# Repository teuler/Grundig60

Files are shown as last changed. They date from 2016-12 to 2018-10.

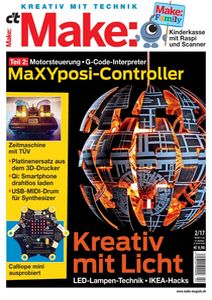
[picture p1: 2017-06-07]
pictures/Make02-17.jpg

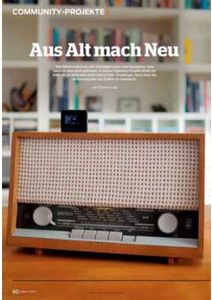
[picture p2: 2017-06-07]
pictures/Make02-17_S61.jpg

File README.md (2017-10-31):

# Grundig60

Converting an old radio from the 60ties (Grundig typ 92) into a DAB radio.

See [wiki](https://github.com/teuler/Grundig60/wiki) for details (German only, sorry).

### Release Notes

* 2017-10-31 - Added two new features: (1) programs are better distributed across the available capacitance range of the station dial, and (2) a function was added to mute the radio during the commercial break until the news starts.
* 2017-07-23 - Bug fix: Recall last station when radio is switched on and "Ton" dial is clamping the station (see below).
* 2017-06-07 - Added [reference](https://github.com/teuler/Grundig60/wiki) to a short presentation as Community Project in the German Make-Magzin 02/2017.
* 2017-05-07 - Added a work-around for the problem that when too many stations are found, the radio tends to oscillate between stations due to the sensitve (capacitative) station dial. Now the "Ton" dial can be used to "clamp" the selected station (for details, see [wiki](https://github.com/teuler/Grundig60/wiki/Endzustand)).
* 2016-12-30 - First "finale" version of the software.
* 2016-12-14 - Implemented a procedure for DAB autoseek, including (German) instructions on the OLED display. Partially solved the problem with the high sensitivity of the station dial; this fix prevents the radio from jumping back and forth between stations.

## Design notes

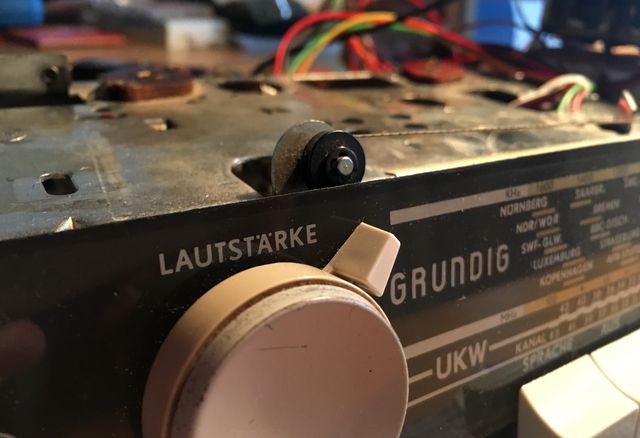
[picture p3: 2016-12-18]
pictures/pic041.jpg

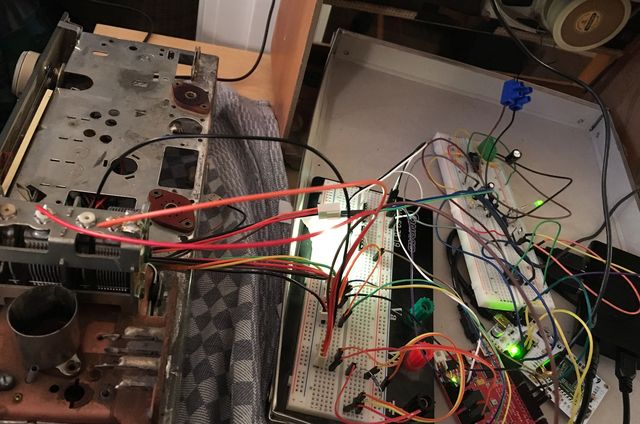
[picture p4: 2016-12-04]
pictures/pic021.jpg

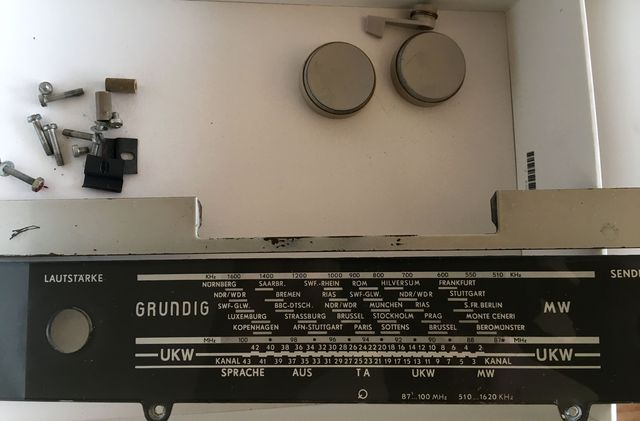
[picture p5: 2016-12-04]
pictures/pic011.jpg

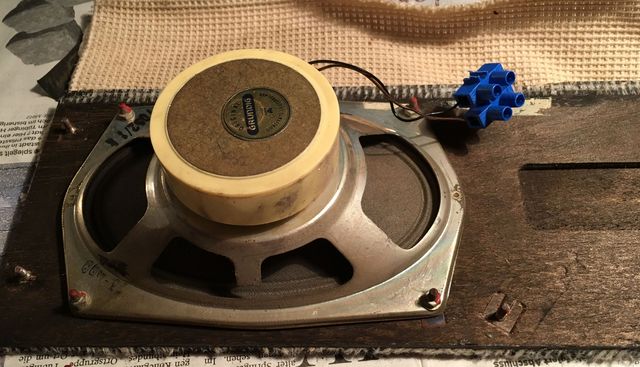
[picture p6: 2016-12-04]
pictures/pic028.jpg

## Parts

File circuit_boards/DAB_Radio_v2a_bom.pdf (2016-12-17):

# Bill of Materials: DAB_Radio_v2a.fzz

E:/User/Dropbox/__ROS/__Circuit boards/board_DAB radio/DAB_Radio_v2a.fzz
Samstag, Dezember 17 2016, 17:52:00

# Assembly List

Label | Part Type | Properties
aux | Audio Jack (TRS)
| 3.5mm | Paket PG203J [THT]; Größe 3.5 mm; Variante variant 1; channels Stereo (TRS)
C1 | Electrolytic
| Capacitor | Paket 100 mil [THT, electrolytic]; Kapazität 220µF; Spannung 6.3V
C2 | Electrolytic
| Capacitor | Paket 100 mil [THT, electrolytic]; Kapazität 1µF; Spannung 6.3V
C3 | Electrolytic
| Capacitor | Paket 100 mil [THT, electrolytic]; Kapazität 1µF; Spannung 6.3V
C4 | Electrolytic
| Capacitor | Paket 100 mil [THT, electrolytic]; Kapazität 1µF; Spannung 6.3V
C5 | Electrolytic
| Capacitor | Paket 100 mil [THT, electrolytic]; Kapazität 1µF; Spannung 6.3V
C6 | Ceramic Capacitor | Paket 100 mil [THT, multilayer]; Kapazität 0.47µF; Spannung 6.3V
C7 | Ceramic Capacitor | Paket 100 mil [THT, multilayer]; Kapazität 0.47µF; Spannung 6.3V
C8 | Electrolytic
| Capacitor | Paket 100 mil [THT, electrolytic]; Kapazität 1µF; Spannung 6.3V

### DAB radio

shield_v1 | Seeeduino Mega | input voltage 6-20V; clock speed 16 MHz; operating voltage 3.3V / 5V
IC1 | IC | Beinchenabstand 300mil; Paket DIP (Dual Inline) [THT]; Beinchen 16; true;
| | Chip-Beschriftung IC; Lochgröße 1.0mm,0.508mm; Bauteilnummer TDA7053A
IC2 | Basic FET
| P-Channel | Paket TO220 [THT]; Typ p-channel; Bauteilnummer IRF5305
IC3 | IC3 | Beinchenabstand 300mil; Paket DIP (Dual Inline) [THT]; Beinchen 10; true;
| | Chip-Beschriftung IC3; Lochgröße 1.0mm,0.508mm; Bauteilnummer ST3002H5W
J10 | Generic female
| header - 4 pins | Beinchenabstand 0.1in (2.54mm); Beinchen 4; Paket THT; Form ♀ (female);
| | Lochgröße 1.0mm,0.508mm; row single
J11 | Generic female
| header - 2 pins | Beinchenabstand 0.1in (2.54mm); Beinchen 2; Paket THT; Form ♀ (female);
| | Lochgröße 1.0mm,0.508mm; row single
J12 | Generic female
| header - 6 pins | Beinchenabstand 0.1in (2.54mm); Beinchen 6; Paket THT; Form ♀ (female);
| | Lochgröße 1.0mm,0.508mm; row single
J1_DAB | Generic female
| header - 4 pins | Beinchenabstand 0.1in (2.54mm); Beinchen 4; Paket THT; Form ♀ (female);
| | Lochgröße 1.0mm,0.508mm; row single
Fritzing Bill of Materials | file:///E:/User/Dropbox/__GIT/Grundig60/circuit_board/DAB_Radio_...
1 von 3 | 17.12.2016 18:00

Label | Part Type | Properties
J2_LED | Generic female

### header - 3 pins

Beinchenabstand 0.1in (2.54mm); Beinchen 3; Paket THT; Form ♀ (female); Lochgröße 1.0mm,0.508mm; row single

J3_power | Generic female

### header - 2 pins

Beinchenabstand 0.1in (2.54mm); Beinchen 2; Paket THT; Form ♀ (female); Lochgröße 1.0mm,0.508mm; row single

J4 | Generic female

### header - 3 pins

Beinchenabstand 0.1in (2.54mm); Beinchen 3; Paket THT; Form ♀ (female); Lochgröße 1.0mm,0.508mm; row single

J6_I2C | Generic female

### header - 4 pins

Beinchenabstand 0.1in (2.54mm); Beinchen 4; Paket THT; Form ♀ (female); Lochgröße 1.0mm,0.508mm; row single

J7 | Generic female

### header - 4 pins

Beinchenabstand 0.1in (2.54mm); Beinchen 4; Paket THT; Form ♀ (female); Lochgröße 1.0mm,0.508mm; row single

J8 | Generic female

### header - 2 pins

Beinchenabstand 0.1in (2.54mm); Beinchen 2; Paket THT; Form ♀ (female); Lochgröße 1.0mm,0.508mm; row single

J9 | Generic female

### header - 3 pins

Beinchenabstand 0.1in (2.54mm); Beinchen 3; Paket THT; Form ♀ (female); Lochgröße 1.0mm,0.508mm; row single

L

### Screw terminal - 2 pins

Beinchenabstand 0.1in (2.54mm); Beinchen 2; Paket THT; Lochgröße 1.0mm,0.508mm

LED1 | Green (570nm) LED | Paket 3 mm [THT]; leg yes; Farbe Green (570nm)

R

### Screw terminal - 2 pins

Beinchenabstand 0.1in (2.54mm); Beinchen 2; Paket THT; Lochgröße 1.0mm,0.508mm

R1 | 10kΩ Resistor | Beinchenabstand 400 mil; Paket THT; bands 4; Toleranz ±5%; Widerstand 10kΩ
R2 | 1kΩ Resistor | Beinchenabstand 400 mil; Paket THT; bands 4; Toleranz ±5%; Widerstand 1kΩ
R3 | 330Ω Resistor | Beinchenabstand 400 mil; Paket THT; bands 4; Toleranz ±5%; Widerstand 330Ω
R4 | 10kΩ Resistor | Beinchenabstand 400 mil; Paket THT; bands 4; Toleranz ±5%; Widerstand 10kΩ
R5 | 10kΩ Resistor | Beinchenabstand 400 mil; Paket THT; bands 4; Toleranz ±5%; Widerstand 10kΩ
R6 | 100kΩ Resistor | Beinchenabstand 400 mil; Paket THT; bands 4; Toleranz ±5%; Widerstand 100kΩ
R7 | 8.2kΩ Resistor | Beinchenabstand 400 mil; Paket THT; bands 4; Toleranz ±5%; Widerstand 8.2kΩ
R8 | 8.2kΩ Resistor | Beinchenabstand 400 mil; Paket THT; bands 4; Toleranz ±5%; Widerstand 8.2kΩ
R9 | 1MΩ Resistor | Beinchenabstand 400 mil; Paket THT; bands 4; Toleranz ±5%; Widerstand 1MΩ
R10 | 1MΩ Resistor | Beinchenabstand 400 mil; Paket THT; bands 4; Toleranz ±5%; Widerstand 1MΩ
radio | Audio Jack (TRS)
3.5mm

Paket PG203J [THT]; Größe 3.5 mm; Variante variant 1; channels Stereo (TRS)

# Shopping List

Amount | Part Type | Properties
2 | Audio Jack (TRS) | Paket PG203J [THT]; Größe 3.5 mm; Variante variant 1; channels Stereo (TRS)
2 von 3 | 17.12.2016 18:00

Amount | Part Type | Properties
| 3.5mm

### 1 Electrolytic

| Capacitor | Paket 100 mil [THT, electrolytic]; Kapazität 220µF; Spannung 6.3V

### 5 Electrolytic

| Capacitor | Paket 100 mil [THT, electrolytic]; Kapazität 1µF; Spannung 6.3V
2 | Ceramic Capacitor | Paket 100 mil [THT, multilayer]; Kapazität 0.47µF; Spannung 6.3V
1 | Seeeduino Mega | input voltage 6-20V; clock speed 16 MHz; operating voltage 3.3V / 5V
1 | IC | Beinchenabstand 300mil; Paket DIP (Dual Inline) [THT]; Beinchen 16; true; Chip-Beschriftung IC; Lochgröße 1.0mm,0.508mm; Bauteilnummer TDA7053A
1 | Basic FET P-Channel | Paket TO220 [THT]; Typ p-channel; Bauteilnummer IRF5305
1 | IC3 | Beinchenabstand 300mil; Paket DIP (Dual Inline) [THT]; Beinchen 10; true; Chip-Beschriftung IC3; Lochgröße 1.0mm,0.508mm; Bauteilnummer ST3002H5W

### 4 Generic female

| header - 4 pins | Beinchenabstand 0.1in (2.54mm); Beinchen 4; Paket THT; Form ♀ (female); Lochgröße 1.0mm,0.508mm; row single

### 3 Generic female

| header - 2 pins | Beinchenabstand 0.1in (2.54mm); Beinchen 2; Paket THT; Form ♀ (female); Lochgröße 1.0mm,0.508mm; row single

### 1 Generic female

| header - 6 pins | Beinchenabstand 0.1in (2.54mm); Beinchen 6; Paket THT; Form ♀ (female); Lochgröße 1.0mm,0.508mm; row single

### 3 Generic female

| header - 3 pins | Beinchenabstand 0.1in (2.54mm); Beinchen 3; Paket THT; Form ♀ (female); Lochgröße 1.0mm,0.508mm; row single

### 2 Screw terminal - 2

| pins | Beinchenabstand 0.1in (2.54mm); Beinchen 2; Paket THT; Lochgröße 1.0mm,0.508mm
1 | Green (570nm) LED | Paket 3 mm [THT]; leg yes; Farbe Green (570nm)
3 | 10kΩ Resistor | Beinchenabstand 400 mil; Paket THT; bands 4; Toleranz ±5%; Widerstand 10kΩ
1 | 1kΩ Resistor | Beinchenabstand 400 mil; Paket THT; bands 4; Toleranz ±5%; Widerstand 1kΩ
1 | 330Ω Resistor | Beinchenabstand 400 mil; Paket THT; bands 4; Toleranz ±5%; Widerstand 330Ω
1 | 100kΩ Resistor | Beinchenabstand 400 mil; Paket THT; bands 4; Toleranz ±5%; Widerstand 100kΩ
2 | 8.2kΩ Resistor | Beinchenabstand 400 mil; Paket THT; bands 4; Toleranz ±5%; Widerstand 8.2kΩ
2 | 1MΩ Resistor | Beinchenabstand 400 mil; Paket THT; bands 4; Toleranz ±5%; Widerstand 1MΩ

Exported with Fritzing 0.9.3- http://fritzing.org

3 von 3 | 17.12.2016 18:00

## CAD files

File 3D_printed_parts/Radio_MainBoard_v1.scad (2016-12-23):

include <threads.scad>

b_xrim      = 3;
b_yrim      = 3;
b_dx        = 55;
b_dy        = 72;
b_thickness = 1.5;
b_shift     = 0;

scr_dz      = 6;
scr_dia     = 5;
scr_hole_d  = 3.0;
scr_hole2_d = 5;
pos_scr     = [[b_dx-3-b_xrim ,18+51-b_yrim,0],
               [b_dx-20,10,0],
               [b_dx-29-20,18-3,0],
               [13-b_xrim,b_dy-13-b_yrim,0]];

pos_b       = [-b_dx/2,-b_dy/2, 0];
pos_scr_off = [-b_dx/2,-b_dy/2, 0];


module board() {
 /* difference() {
        union() {
            for(pos=pos_scr) {
                rotate(0, [1,0,0]) translate(pos)
                translate(pos_scr_off)
                translate([scr_dia/2,scr_dia/2,h_from_tube -b_thickness*0.8])
                cylinder($fn=100, h=scr_dz+b_thickness/2, r=scr_dia/2);
            }
            translate(pos_b) 
            cube([b_dx, b_dy, b_thickness]);
        }
        union() {
            for(pos=pos_scr) {
                rotate(0, [1,0,0]) translate(pos) 
                translate(pos_scr_off)
                translate([scr_dia/2,scr_dia/2,-10])
                cylinder($fn=100, h=scr_dz*3, r=scr_hole2_d/2);
            }
            for(pos=pos_scr) {
                rotate(0, [1,0,0]) translate(pos) 
                translate(pos_scr_off)
                translate([scr_dia/2,scr_dia/2,h_from_tube -b_thickness*2])
                cylinder($fn=100, h=scr_dz*2, r=scr_hole_d/2);
            }
        }*/
    
    for(pos=pos_scr) {
        rotate(0, [1,0,0]) translate(pos)
        translate(pos_scr_off)
        translate([scr_dia/2,scr_dia/2,0.25])
        cylinder($fn=100, h=scr_dz+b_thickness, r=scr_dia/2);
    }
    translate(pos_b) 
    cube([b_dx, b_dy, b_thickness]);
}

module threads() {
    for(pos=pos_scr) {
        rotate(0, [1,0,0]) translate(pos) 
        translate(pos_scr_off)
        translate([scr_dia/2,scr_dia/2,-3])
        //cylinder($fn=100, h=scr_dz*2, r=scr_hole_d/2);
        metric_thread(diameter=2.5, pitch=0.45, length=scr_dz+b_thickness+5+10, internal=true);
    }
}

module holes() {
    rotate(0, [1,0,0])
    translate(pos_b)
    translate([b_dx-4,11,-10])
    cylinder($fn=100, h=20, r=4/2);

    rotate(0, [1,0,0])
    translate(pos_b)
    translate([25,27,-10])
    cylinder($fn=100, h=20, r=3/2);

    rotate(0, [1,0,0])
    translate(pos_b)
    translate([b_dx-13,46,-10])
    cylinder($fn=100, h=20, r=3/2);
    
    rotate(0, [1,0,0])
    translate(pos_b)
    translate([28-1.5,2,-10])
    cylinder($fn=100, h=20, r=4/2);

    translate(pos_b) 
    translate([b_dx+b_xrim-30,15,-5]) 
    cube([30, 30, 10]);

    translate(pos_b) 
    translate([-1,-1,-5]) 
    cube([7, 26, 10]);
}

module base() {
    difference() {
        board();
        union() {
            threads();    
            holes();
        }
    }
}

base();





/*
d_wall		= 1.25;
tol			= 0.2;

fr_dx		= 65 +2*d_wall;
fr_dy		= 140; //120 +d_wall;
fr_height  = 30;

lt_dx      = 20;

scr1_dia   = 7;
scr1_ctr_x = -8;
scr1_ctr_dy= 17;

scr2_dia   = 6;
scr_dy_wall= 25;
scr_dx_left= 15;
scr2_pos   = [[scr_dx_left+15,scr_dy_wall+2,d_wall/2], 
			 [scr_dx_left+42.5,scr_dy_wall+2,d_wall/2], 
              [scr_dx_left+15,scr_dy_wall+59,d_wall/2], 
              [scr_dx_left+42.5,scr_dy_wall+59,d_wall/2]];
scr2_height= 6;
scr2_h_dia = 3.0;
scr3_dia   = scr2_dia;
scr3_pos   = [[4,   110,   d_wall/2],
			 [4,   110+21,d_wall/2],			 
			 [4+57,110,   d_wall/2],
			 [4+57,110+21,d_wall/2]];
scr3_height= 11;
scr3_h_dia = scr2_h_dia;


led_dia    = 3;
led_pos    = [[1*fr_dx/6,scr1_ctr_dy/2+fr_height/2, -10],
   			 [3*fr_dx/6,scr1_ctr_dy/2+fr_height/2, -10],
			 [5*fr_dx/6,scr1_ctr_dy/2+fr_height/2, -10]];

bnc_dia    = 10;
bnc_pos    = [[1*fr_dx/6,fr_height/3, -10],
//			 [fr_dx/2,fr_height/3*2, -10-fr_dy]
			 [3*fr_dx/6,fr_height/3, -10]];

module Screw1Holes()
{
	_r		= scr1_dia/2 +tol;
	_x		= scr1_ctr_x;
	_y1		= fr_height/2 +scr1_ctr_dy/2;
	_y2		= fr_height/2 -scr1_ctr_dy/2;
	rotate(90, [1,0,0]) translate([_x,_y1,-10]) 
	cylinder($fn=100, h=20, r=_r);
	rotate(90, [1,0,0]) translate([_x,_y2,-10]) 
	cylinder($fn=100, h=20, r=_r);
};


module LEDHoles()
{
	_r		= led_dia/2 +tol/2;
    for(pos=led_pos) { 
		rotate(90, [1,0,0]) translate(pos) 
		cylinder($fn=100, h=9.5, r=_r);
	}
};

module LEDPosts()
{
	_r		= led_dia/2 +tol/2;
    for(pos=led_pos) { 
		rotate(90, [1,0,0]) translate(pos) translate([0,0,4])
		cylinder($fn=100, h=3+d_wall*2, r=_r+2);
	}
};


module BNCHoles()
{
	_r		= bnc_dia/2 +tol/2;
    for(pos=bnc_pos) { 
		difference() {
			rotate(90, [1,0,0]) translate(pos) 
			cylinder($fn=100, h=20, r=_r);
			rotate(90, [1,0,0]) translate([pos[0]-_r,pos[1]+4.8*_r/6,pos[2]])
			cube([2*_r,5,25]);
		}	
	}
};

module cableHoles()
{
	_x		= fr_dx/3*2;
	_y 		= fr_dx/7;
	rotate(90, [1,0,0]) translate([_x,_y,-fr_dy-10]) 
	cylinder($fn=100, h=20, r=7.5);
}

module FrontPlateHoles()
{
	LEDHoles();
	BNCHoles();
}

module BaseplateHoles()
{
    _dx   = fr_dx/4;
    _dy   = fr_dx/4;
    _f    = 1.4;
    _d    = 0.10*_dx;
    _z    = -5;
    _dyst = 1.65;
    _yoff = 0.3;
    for(i=[0,1.05,2,3.05]) {
	    translate([0.50*_dx-_d,(_yoff+_dyst*i)*_dx,_z]) cube([_dx*_f,_dy,10]);
    		translate([2.25*_dx-_d,(_yoff+_dyst*i)*_dx,_z]) cube([_dx*_f,_dy,10]);   
    }
}

module RC_Box()
{
	difference() 
	{
		difference()
		{
			cube([fr_dx, fr_dy, fr_height]);
			translate([d_wall,d_wall*2,d_wall]) cube([fr_dx-2*d_wall,fr_dy-3*d_wall,fr_height]);
		}
    		BaseplateHoles();
	}

    difference()
    {
		translate([-lt_dx,0,0]) cube([lt_dx, d_wall*2, fr_height]);
		Screw1Holes();
    }

	rotate(-90, [0,0,1])
    for(pos=scr2_pos) { 
		rotate(90, [0,0,1]) translate(pos) 
		difference() {
			cylinder($fn=100, h=scr2_height, r=scr2_dia/2);
			cylinder($fn=100, h=scr2_height+5, r=scr2_h_dia/2);
		}
	}
	rotate(-90, [0,0,1])
    for(pos=scr3_pos) { 
		rotate(90, [0,0,1]) translate(pos) 
		difference() {
			cylinder($fn=100, h=scr3_height, r=scr3_dia/2);
			cylinder($fn=100, h=scr3_height+5, r=scr3_h_dia/2);
		}
	}
	LEDPosts();
}

difference()
{
	RC_Box();
	FrontPlateHoles();
	cableHoles();
}
*/

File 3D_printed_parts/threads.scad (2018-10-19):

/*
 * Dan Kirshner - dan_kirshner@yahoo.com
 *
 * You are welcome to make free use of this software.  Retention of my 
 * authorship credit would be appreciated.
 *
 * Version 1.3.  2013-12-01   Correct loop over turns -- don't have early cut-off
 * Version 1.2.  2012-09-09   Use discrete polyhedra rather than linear_extrude()
 * Version 1.1.  2012-09-07   Corrected to right-hand threads!
 */

// Examples:
//metric_thread(8, 1, 10);
//english_thread(1/4, 20, 1);

// Rohloff hub thread:
//metric_thread(34, 1, 10, internal=true, n_starts=6);



//metric_thread(8, 2, 4);



// ----------------------------------------------------------------------------
pi = 3.14159265;


// ----------------------------------------------------------------------------
function segments(diameter) = min(50, ceil(diameter*6));


// ----------------------------------------------------------------------------
// internal - true = clearances for internal thread (e.g., a nut).
//            false = clearances for external thread (e.g., a bolt).
//            (Internal threads should be "cut out" from a solid using
//            difference()).
// n_starts - Number of thread starts (e.g., DNA, a "double helix," has
//            n_starts=2).  See wikipedia Screw_thread.
module metric_thread(diameter=8, pitch=1, length=1, internal=false, n_starts=1)
{
   // Number of turns needed.
   n_turns = floor(length/pitch);
   n_segments = segments(diameter);
   h = pitch * cos(30);

   union() {
      intersection() {
         // Start one below z = 0.  Gives an extra turn at each end.
         for (i=[-1*n_starts : n_turns+1]) {
            translate([0, 0, i*pitch]) {
               metric_thread_turn(diameter, pitch, internal, n_starts);
            }
         }

         // Cut to length.
         translate([0, 0, length/2]) {
            cube([diameter*1.1, diameter*1.1, length], center=true);
         }
      }

      // Solid center, including Dmin truncation.
      if (internal) {
         cylinder(r=diameter/2 - h*5/8, h=length, $fn=n_segments);
      } else {

         // External thread includes additional relief.
         cylinder(r=diameter/2 - h*5.3/8, h=length, $fn=n_segments);
      }
   }
}


// ----------------------------------------------------------------------------
// Input units in inches.
// Note: units of measure in drawing are mm!
module english_thread(diameter=0.25, threads_per_inch=20, length=1,
                      internal=false, n_starts=1)
{
   // Convert to mm.
   mm_diameter = diameter*25.4;
   mm_pitch = (1.0/threads_per_inch)*25.4;
   mm_length = length*25.4;

   echo(str("mm_diameter: ", mm_diameter));
   echo(str("mm_pitch: ", mm_pitch));
   echo(str("mm_length: ", mm_length));
   metric_thread(mm_diameter, mm_pitch, mm_length, internal, n_starts);
}


// ----------------------------------------------------------------------------
module metric_thread_turn(diameter, pitch, internal, n_starts)
{
   n_segments = segments(diameter);
   fraction_circle = 1.0/n_segments;
   for (i=[0 : n_segments-1]) {
      rotate([0, 0, i*360*fraction_circle]) {
         translate([0, 0, i*n_starts*pitch*fraction_circle]) {
            thread_polyhedron(diameter/2, pitch, internal, n_starts);
         }
      }
   }
}


// ----------------------------------------------------------------------------
// z (see diagram) as function of current radius.
// (Only good for first half-pitch.)
function z_fct(current_radius, radius, pitch)
   = 0.5*(current_radius - (radius - 0.875*pitch*cos(30)))
                                                       /cos(30);

// ----------------------------------------------------------------------------
module thread_polyhedron(radius, pitch, internal, n_starts)
{
   n_segments = segments(radius*2);
   fraction_circle = 1.0/n_segments;

   h = pitch * cos(30);
   outer_r = radius + (internal ? h/20 : 0); // Adds internal relief.
   //echo(str("outer_r: ", outer_r));


   inner_r = radius - 0.875*h; // Does NOT do Dmin_truncation - do later with
                               // cylinder.

   // Make these just slightly bigger (keep in proportion) so polyhedra will
   // overlap.
   x_incr_outer = outer_r * fraction_circle * 2 * pi * 1.005;
   x_incr_inner = inner_r * fraction_circle * 2 * pi * 1.005;
   z_incr = n_starts * pitch * fraction_circle * 1.005;

   /*    
    (angles x0 and x3 inner are actually 60 deg)

                          /\  (x2_inner, z2_inner) [2]
                         /  \
   (x3_inner, z3_inner) /    \
                  [3]   \     \
                        |\     \ (x2_outer, z2_outer) [6]
                        | \    /
                        |  \  /|
             z          |   \/ / (x1_outer, z1_outer) [5]
             |          |   | /
             |   x      |   |/
             |  /       |   / (x0_outer, z0_outer) [4]
             | /        |  /     (behind: (x1_inner, z1_inner) [1]
             |/         | /
    y________|          |/
   (r)                  / (x0_inner, z0_inner) [0]

   */

   x1_outer = outer_r * fraction_circle * 2 * pi;

   z0_outer = z_fct(outer_r, radius, pitch);
   //echo(str("z0_outer: ", z0_outer));

   //polygon([[inner_r, 0], [outer_r, z0_outer], 
   //        [outer_r, 0.5*pitch], [inner_r, 0.5*pitch]]);
   z1_outer = z0_outer + z_incr;

   // Rule for triangle ordering: look at polyhedron from outside: points must
   // be in clockwise order.
   polyhedron(
      points = [
                [-x_incr_inner/2, -inner_r, 0],                                    // [0]
                [x_incr_inner/2, -inner_r, z_incr],                    // [1]
                [x_incr_inner/2, -inner_r, pitch + z_incr],            // [2]
                [-x_incr_inner/2, -inner_r, pitch],                                // [3]

                [-x_incr_outer/2, -outer_r, z0_outer],                             // [4]
                [x_incr_outer/2, -outer_r, z0_outer + z_incr],         // [5]
                [x_incr_outer/2, -outer_r, pitch - z0_outer + z_incr], // [6]
                [-x_incr_outer/2, -outer_r, pitch - z0_outer]                      // [7]
               ],

      triangles = [
                [0, 3, 4],  // This-side trapezoid, bottom
                [3, 7, 4],  // This-side trapezoid, top

                [1, 5, 2],  // Back-side trapezoid, bottom
                [2, 5, 6],  // Back-side trapezoid, top

                [0, 1, 2],  // Inner rectangle, bottom
                [0, 2, 3],  // Inner rectangle, top

                [4, 6, 5],  // Outer rectangle, bottom
                [4, 7, 6],  // Outer rectangle, top

                [7, 2, 6],  // Upper rectangle, bottom
                [7, 3, 2],  // Upper rectangle, top

                [0, 5, 1],  // Lower rectangle, bottom
                [0, 4, 5]   // Lower rectangle, top
               ]
   );
}

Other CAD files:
3D_printed_parts/Radio_DAB_v2b.scad

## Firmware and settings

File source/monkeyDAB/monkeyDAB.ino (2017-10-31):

//--------------------------------------------------------------------------------
// project : monkeyDAB
// module  : monkeyDAB
//           DAB radio based on monkey DAB board
// author  : Thomas Euler
// history : 2016-10-08, created
//           2017-05-07, tone dial setting to "clamp" station
//           2017-07-15, check for station "clamp" only after checking for the 
//                       selected station at start-up
//
//--------------------------------------------------------------------------------
#define  GERMAN_TEXT
#define  USE_HSV
#include <WS2812.h>
#include <EEPROM.h>
#include <Wire.h>
#include <Adafruit_GFX.h>
#include <Adafruit_SSD1306.h>
#include "monkeyRadio.h"

//--------------------------------------------------------------------------------
// Global definitions
//
#define          SER_HOST           (*SerHostStream)
#define          SER_DEBUG_OUT      (*SerDebugStream)
#define          SER_MONKEY_RADIO   Serial1
#define          SER_DEBUG          Serial

//#define        LOG_INTERF_CHANGES 
//#define        LOG_CAP_TO_PROG    

//                                  0   -> TX0
//                                  1   -> RX0
#define          PIN_LED            2
#define          PIN_BUTTON_SPRACHE 3
//                                  4   -> DAB SHNT
//                                  5   -> DAB SHDN
#define          PIN_DISPLAY_RST    6
#define          PIN_DIAL_VC        7
//                                  8
//                                  10
#define          PIN_RELAY          11
#define          PIN_AMP_POWER      12
#define          PIN_CAP_IN         A0
#define          PIN_CAP_OUT        A1
//                                  A2
#define          PIN_DIAL_EXTEND    A3
#define          PIN_DIAL_TON       A4
#define          PIN_BUTTON_MW      A5
#define          PIN_BUTTON_UKW     A6
#define          PIN_BUTTON_TA      A7

#define          ID_LED_INFO        0
#define          ID_LED_INFO2       1
#define          LED_COUNT          2
#define          ID_COLOR_PLAYING   0
#define          ID_COLOR_TUNING    1
#define          ID_COLOR_STARTING  2
#define          ID_COLOR_ERROR     3
#define          ID_COLOR_AUTOSEEK  4
#define          ID_COLOR_AUX       5
#define          COLOR_COUNT        6
#define          LED_INFO_MIN       200
#define          LED_INFO_MAX       255
#define          LED_FLICKER_MIN    180
#define          LED_FLICKER_MAX    220
#define          LED_FLICKER_DI     10
#define          LED_FLICKER_DT     40

#define          RELAY_RADIO        LOW
#define          RELAY_AUX          HIGH

#define          EEPROM_START       0
#define          EEPROM_TO_DEFAULT  false

#define          CONTROL_BUTTON     0
#define          CONTROL_DIAL_R     1
#define          CONTROL_DIAL_C     2

#define          BUTTON_SPRACHE     0
#define          BUTTON_TA          1
#define          BUTTON_UKW         2
#define          BUTTON_MW          3
#define          DIAL_PROGRAM       4
#define          DIAL_TON           5
#define          CONTROL_COUNT      6

#define          DIAL_TON_THRES_1   7
#define          DIAL_TON_THRES_2   20

#define          BUTTON_DEBOUNCE_MS 100L
#define          DIAL_C_DENOISE_MS  5L
#define          DIAL_R_DENOISE_MS  5L
#define          DIAL_R_DIV         10

#define          CAP_IN_TO_GND      24.48
#define          CAP_R_PULLUP       34.8
#define          MAX_ADC_VALUE      1023

#define          RADIO_UPDATE_MS    1000
#define          LOOP_DELAY_MS      10

#define          USE_DISPLAY
#define          DISPLAY_TIME_WSEC  false

#define          COUNTDOWN_DIV      10
#define          COUNTDOWN_MAX_S    5

#define          MAX_DAB_PROGS      64

//--------------------------------------------------------------------------------
// Finite stae machine definitions
//
#define          FSM_UNDEFINED              0
#define          FSM_OFF                    1
#define          FSM_AUX                    2
#define          FSM_DAB_PLAY               3
#define          FSM_DAB_AUTOSEARCH         4
#define          FSM_DAB_AUTOSEARCH_FAILED  5
#define          FSM_NOT_IMPLEMENTED        6
#define          LAST_FSM_STATE             6

char* FSMStr[LAST_FSM_STATE +1] = {
  #ifdef GERMAN_TEXT
  "Nicht definiert", "Aus",
  "AUX", "DAB",
  "Sendersuchlauf ...", "Sendersuchlauf gescheitert",
  "Nicht implementiert"
  #else
  "undefined", "off",
  "playing AUX", "playing DAB",
  "autosearch running", "autosearch failed",
  "not implemented"
  #endif
  };

//--------------------------------------------------------------------------------
// Global variables
//
HardwareSerial*  SerHostStream;     // port for monkey DAB board
HardwareSerial*  SerDebugStream;    // port for debug messages and key-base UI
WS2812           LEDs(LED_COUNT);   // LED(s)
#ifdef USE_DISPLAY
Adafruit_SSD1306 Display(PIN_DISPLAY_RST);
#endif

typedef struct {
  char           progDAB, progDABType, DABService;
  char           progName[MAX_TEXT_BUFFER], progAbbr[MAX_TEXT_BUFFER];
  char           mode, state, stereo, playMode;
  bool           isProgChanged, isMute;
  int            bitError, dataRate, qualityDAB;
  float          lastQualityDAB;
  char           signalStrength;  // DAB signal strength
  char           volume;          // current volume
  String         RTC_timeDateStr; // current time and date as string
} radio_state_t;

typedef struct {
  bool           isNew;           // has EEPROM never been written
  char           progDAB;         // default DAB program index
  char           volume;          // default software volume
  int            minCap, maxCap;  // minimum and maximum C [pF] of program dial
  // ...
  byte           h[COLOR_COUNT], s[COLOR_COUNT], v[COLOR_COUNT];
} radio_config_t;

typedef struct {
  uint16_t       x, y, color, bgrColor, size;
  bool           doWrap;
  String         text;
} text_t;

// Represents an interface element, a button or different kinds of dials
//   val       := current value of the element, with 0 or 1 for buttons and
//                a dial-type specific value for dials
//   isChanged := if val has changed since the last check
//
typedef struct {
  uint8_t        pin, pin2, type;
  char           name[8];
  bool           rawState, state, lastState, readingState, highState;
  int            readingVal, lastVal, val;
  bool           isChanged;
  float          cap;
  unsigned long  tLast;
} control_t;


radio_state_t    Radio;
radio_config_t   Conf;

RTC_time_t       RTC_time, RTC_time1;
/*
typedef struct {
  byte            second, minute, hour, day, month, year;
  bool            isOk;
} RTC_time_t;
*/

char             ch;
String           sTemp;
int              res, nProg, iProg, iPrevProg, dirProg;
unsigned long    tLastUpdate;
bool             failed;
bool             isAmpPowerOn, relaySource;
BBE_EQ_t         BBE_EQ;

int              FSM_state, FSM_lastState;
int              nCapBins;
//float          dCapBin;
bool             isControlChanged;
bool             isDisplayOn;
bool             lastBusy;
bool             isMutedByUser, doUserUnmute, didUnmuteOnTime;
bool             isProgDialLocked, isFirstUpdateFSM, isCommercialMute;

control_t        Controls[CONTROL_COUNT] = {
  {PIN_BUTTON_SPRACHE, 0,   CONTROL_BUTTON, "SPRACHE",
   LOW, LOW,  HIGH, LOW, LOW,  0,0,-1, false, 0.0, 0L},
  {PIN_BUTTON_TA, 0,        CONTROL_BUTTON, "TA",
   LOW, LOW,  HIGH, LOW, LOW,  0,0,-1, false, 0.0, 0L},
  {PIN_BUTTON_UKW, 0,       CONTROL_BUTTON, "UKW",
   LOW, HIGH, LOW,  LOW, HIGH, 0,0,-1, false, 0.0, 0L},
  {PIN_BUTTON_MW, 0,        CONTROL_BUTTON, "MW",
   LOW, LOW,  HIGH, LOW, LOW,  0,0,-1, false, 0.0, 0L},
  {PIN_CAP_IN, PIN_CAP_OUT, CONTROL_DIAL_C, "SENDER",
   LOW, LOW,  LOW,  LOW, LOW,  0,0,-1, false, 0.0, 0L},
  {PIN_DIAL_TON, 0,         CONTROL_DIAL_R, "TON",
   LOW, LOW,  LOW,  LOW, LOW,  0,0,-1, false, 0.0, 0L}};

//--------------------------------------------------------------------------------
// Constants and variables related to arranging DAB programs across the 
// (capacitance) range of the station dial 
//
const int        dBordMin  = 1;
const int        nBordDef  = 15;
const int        nTrials   = 50;
const float      lambDef   = 0.2;
const float      euler     = 2.71828;

int              ProgBorders[MAX_DAB_PROGS];

//--------------------------------------------------------------------------------
//
//--------------------------------------------------------------------------------
void initOtherHardware()
{
  pinMode(PIN_AMP_POWER, OUTPUT);
  switchAmpPower(true);
  pinMode(PIN_RELAY, OUTPUT);
  switchRelayToSource(RELAY_RADIO);
}

//--------------------------------------------------------------------------------
void setup()
{
  // Initialize
  //
  Radio.progDAB        = 10;
  Radio.progName[0]    = 0;
  Radio.progAbbr[0]    = 0;
  Radio.state          = PLAY_STATUS_INVALID;
  Radio.mode           = STREAM_MODE_DAB;
  Radio.stereo         = -1;
  Radio.playMode       = -1;
  Radio.isProgChanged  = false;
  Radio.bitError       = 0;
  Radio.dataRate       = 0;
  Radio.signalStrength = 0;
  Radio.volume         = 10;
  Radio.qualityDAB     = 0;
  Radio.lastQualityDAB = 50;
  Radio.DABService     = DAB_SERVICE_UNKNOWN;
  Radio.isMute         = false;

  tLastUpdate          = millis();
  dirProg              = 1;
  iPrevProg            = 0;
  FSM_state            = FSM_UNDEFINED;
  FSM_lastState        = FSM_state;
  isControlChanged     = false;
  isDisplayOn          = true;
  lastBusy             = true;
  isProgDialLocked     = false;
  isFirstUpdateFSM     = true;
  isMutedByUser        = false;
  doUserUnmute         = false;
  didUnmuteOnTime      = false;

  BBE_EQ.BBEOn         = 2;
  BBE_EQ.EQMode        = EQ_MODE_JAZZ;
  BBE_EQ.BBELo         = 5;  // 0..24, 0~12dB, 0.5dB/step
  BBE_EQ.BBEHi         = 0;  // 0..24, 0~12dB, 0.5dB/step
  BBE_EQ.BBECFreq      = 0;  // 0..1, 595Hz or 1000Hz
  BBE_EQ.BBEMachFreq   = 60; // 60, 90, 120, 150Hz
  BBE_EQ.BBEMachGain   = 0;  // 0, 4, 8, 12dB
  BBE_EQ.BBEMachQ      = 1;  // 1 or 3
  BBE_EQ.BBESurr       = 0;  // 0~10dB
  BBE_EQ.BBEMp         = 0;  // 0~10dB
  BBE_EQ.BBEHpF        = 0;  // 0 or 20~250Hz(10Hz/step), 0=off
  BBE_EQ.BBEHiMode     = 0;  // 0~12dB

  SER_DEBUG.begin(baudSerMonkeyRadio);
  delay(50);

  // Initialize modules
  //
  readConfig();
  initOtherHardware();
  initControls();
  initLEDs();
  #ifdef USE_DISPLAY
  initDisplay();
  #endif
  initControls();
  // ...

  // Open COM link to radio
  //
  SER_MONKEY_RADIO.begin(baudSerMonkeyRadio);
  SER_MONKEY_RADIO.setTimeout(tOutSerMonkeyRadio_ms);

  SerHostStream  = &SER_MONKEY_RADIO;
  SerDebugStream = &SER_DEBUG;
  monkeyRadio.setStream(&SER_HOST, &SER_DEBUG_OUT);
  delay(100);

  if(!monkeyRadio.openRadioPort(false)) {
    SER_DEBUG.println(F("ERROR: failed to open radio"));
  }
  else {
    // Link to radio established
    //
    monkeyRadio.getTotalDABProgramsFromDB();
    if(monkeyRadio.getDABProgramCount() == 0) {
      // No DAB programs in database, start search ...
      //
      monkeyRadio.DABAutoSearch(DAB_MIN_PROG, DAB_MAX_PROG, (displayFunc)displayMsg);
      monkeyRadio.getTotalDABProgramsFromDB();
    }
    monkeyRadio.setVolume(Radio.volume);
    monkeyRadio.setBBEEQ(BBE_EQ);
    monkeyRadio.syncRTC(true);

    if(monkeyRadio.getDABProgramCount() > 0) {
      // DAB programs are available
      //
      updateProgramDialParams();
      Radio.isProgChanged = true;
      // ...
    //FSM_state = FSM_DAB_PLAY;
    }
  }
  handleKeyInput('?');
}

//--------------------------------------------------------------------------------
void loop() {
  // Check if a command arrived via the terminal
  //
  if(Serial.available()) {
    ch = Serial.read();
    if(!handleKeyInput(ch)) {
      SER_DEBUG.println(F("ERROR: unknown key"));
      // ...
    }
  }
  // Update representation of interface hardware and finite state machine
  //
  updateControlStates();
  updateFSM();

  // If program has changed, switch station ...
  //
  if(Radio.isProgChanged) {
    monkeyRadio.quiet(true);

    // Check if selected index is an audio stream, if not, go to the next
    // or stay if at the end of the range
    //
    nProg  = monkeyRadio.getDABProgramCount();
    iProg  = Radio.progDAB;
    res    = monkeyRadio.getServCompType(iProg);
    failed = false;
    while(!failed && (res != DAB_SERVICE_DAB) && (res != DAB_SERVICE_DAB_PLUS)) {
      if(dirProg > 0) {
        if(iProg < nProg-1)
          iProg++;
        else
          failed = true;
      }
      else {
       if(iProg > 0)
          iProg--;
        else
          failed = true;
      }
      res = monkeyRadio.getServCompType(iProg);
    }
    if(!failed)
      Radio.progDAB = iProg;
    else {
      Radio.progDAB = iPrevProg;
    }
    // Switch to new program
    // (or stay with previous one, if there is no next one)
    //
    monkeyRadio.playStream(STREAM_MODE_DAB, Radio.progDAB);
    Radio.state = monkeyRadio.getPlayStatus();
    flickerLED_Info(ID_COLOR_TUNING, LED_FLICKER_MIN, LED_FLICKER_MAX, LED_FLICKER_DI, LED_FLICKER_DT, true);
    while(Radio.state != PLAY_STATUS_PLAY) {
      flickerLED_Info(ID_COLOR_TUNING, 0, 0, 0, 0, false);
      Radio.state = monkeyRadio.getPlayStatus();
    }
    monkeyRadio.quiet(false);
    tLastUpdate = 0;
    #ifdef USE_DISPLAY
    displayClear();
    #endif
    Radio.isProgChanged = false;
  }

  // If muted by user, check if full or half hour is coming up to unmute
  //
  if(isMutedByUser) {
    if(!RTC_time.isOk) {
      // Unmute now as the time seems not to be available
      //
      doUserUnmute = true;
    }
    else {
      // Check time ...
      //
      if(!Radio.isMute) {
        monkeyRadio.hardMute();
        monkeyRadio.setVolume(0);
        Radio.isMute = true;
        RTC_time1    = RTC_time;
        getNextFullOrHalfHour(&RTC_time1);
        RTCTimeToTimeDateStr(RTC_time1, sTemp, false);
        SER_DEBUG.print(F("Mute until "));
        SER_DEBUG.print(sTemp);
        SER_DEBUG.println();
        //...
      }
      else {
        doUserUnmute    = isItTime(&RTC_time, &RTC_time1);
        didUnmuteOnTime = doUserUnmute;
      }  
    }
  }
  if(doUserUnmute) {
    // Unmute ...
    //
    monkeyRadio.hardUnMute();
    monkeyRadio.setVolume(Radio.volume);
    Radio.isMute  = false;
    doUserUnmute  = false;
    isMutedByUser = false;
  }

  // Update radio info at a defined interval
  //
  if(millis() > (tLastUpdate +RADIO_UPDATE_MS)) {
    updateStateInfo();
    #ifdef USE_DISPLAY
    displayInfo();
    #endif
    tLastUpdate = millis();
  }
  // Delay main loop to allow hardware to keep up
  //
  if(LOOP_DELAY_MS > 0)
    delay(LOOP_DELAY_MS);
}
//--------------------------------------------------------------------------------

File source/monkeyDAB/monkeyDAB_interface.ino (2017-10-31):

//--------------------------------------------------------------------------------
// project : monkeyDAB
// module  : monkeyDAB_interface
//           hardware interface, such as buttons and dials
// author  : Thomas Euler
// history : 2016-11-03, created
//           2017-05-07, tone dial setting to "clamp" station
//           2017-10-29, trying to distribute the stations/programs better across
//                       the station dial's capacitance range, acknowledging its
//                       non-linearity
//--------------------------------------------------------------------------------
void initControls()
{
  SER_DEBUG.print(F("Initializing controls ..."));

  // Set all analog inputs by default as floating to prevent them to interfer
  // with the capacitance measurements
  //
  for(byte j=A0; j<A7; j++) {
    pinMode(j, INPUT);
  }
  pinMode(PIN_DIAL_VC, OUTPUT);
  digitalWrite(PIN_DIAL_VC, LOW);

  // Initialize all controls and get a first readout
  //
  for(byte j=0; j<CONTROL_COUNT; j++) {
    switch(Controls[j].type) {
      case CONTROL_BUTTON :
        pinMode(Controls[j].pin, INPUT_PULLUP);
        delay(10);
        Controls[j].rawState   = digitalRead(Controls[j].pin);
        Controls[j].lastState  = Controls[j].rawState;
        Controls[j].state      = (Controls[j].rawState == Controls[j].highState);
        Controls[j].val        = int(Controls[j].state);
        Controls[j].tLast      = millis();
        Controls[j].isChanged  = true;
        break;

      case CONTROL_DIAL_C :
        pinMode(Controls[j].pin2, OUTPUT);
        pinMode(Controls[j].pin, OUTPUT);
        delay(10);
        Controls[j].cap        = readDialCapacitance(Controls[j].pin, Controls[j].pin2);
      //Controls[j].readingVal = int((Controls[j].cap -(float)Conf.minCap) /dCapBin);
      //Controls[j].readingVal = constrain(Controls[j].readingVal, 0, nCapBins-1);
        Controls[j].readingVal = getProgFromBins(nCapBins, Controls[j].cap);
        Controls[j].val        = Controls[j].readingVal;
        Controls[j].tLast      = millis();
        Controls[j].isChanged  = true;
        break;

      case CONTROL_DIAL_R :
        Controls[j].readingVal = readDialVoltage(Controls[j].pin);
        Controls[j].val        = Controls[j].readingVal;
        Controls[j].tLast      = millis();
        Controls[j].isChanged  = true;
        break;
    }
  }
  // Handle interactions between hardware controls
  //
  correctControlStates();

  SER_DEBUG.println(F("  done"));
}

//--------------------------------------------------------------------------------
void updateControlStates()
{
  // Check for robust changes of the controls' state
  // (debounce buttons and denoise dials)
  //
  for(int j=0; j<CONTROL_COUNT; j++) {
    Controls[j].isChanged = false;

    switch(Controls[j].type) {
      case CONTROL_BUTTON :
        // A button
        //
        Controls[j].readingState = digitalRead(Controls[j].pin);
        if(Controls[j].readingState != Controls[j].lastState) {
          Controls[j].tLast = millis();
        }
        if((millis() -Controls[j].tLast) > BUTTON_DEBOUNCE_MS) {
          Controls[j].isChanged  = (Controls[j].readingState != Controls[j].rawState);
          if(Controls[j].isChanged) {
            Controls[j].rawState = Controls[j].readingState;
            Controls[j].state    = (Controls[j].rawState == Controls[j].highState);
            Controls[j].val      = int(Controls[j].state);
          }
        }
        Controls[j].lastState = Controls[j].readingState;
        break;

      case CONTROL_DIAL_C :
        // A dial that uses a tunable capacitance
        //
        Controls[j].cap          = readDialCapacitance(Controls[j].pin, Controls[j].pin2);
      //Serial.println(Controls[j].cap);
      //Controls[j].readingVal   = (Controls[j].cap -(float)Conf.minCap) /dCapBin;
      //Controls[j].readingVal   = int(constrain(Controls[j].readingVal, 0, nCapBins-1));
        Controls[j].readingVal   = getProgFromBins(nCapBins, Controls[j].cap);
        if(Controls[j].readingVal != Controls[j].lastVal) {
          Controls[j].tLast = millis();
        }
        if((millis() -Controls[j].tLast) > DIAL_C_DENOISE_MS) {
        //Controls[j].isChanged = (Controls[j].readingVal != Controls[j].val);
          Controls[j].isChanged = (abs(Controls[j].readingVal -Controls[j].val) > 1);
          if(Controls[j].isChanged) {
            Controls[j].val = Controls[j].readingVal;
          }
        }
        Controls[j].lastVal = Controls[j].readingVal;
        break;

      case CONTROL_DIAL_R :
        // A dial that uses a tunable resistor (poti)
        //
        Controls[j].readingVal   = readDialVoltage(Controls[j].pin) /DIAL_R_DIV;
        if(Controls[j].readingVal != Controls[j].lastVal) {
          Controls[j].tLast = millis();
        }
        if((millis() -Controls[j].tLast) > DIAL_R_DENOISE_MS) {
          Controls[j].isChanged = (Controls[j].readingVal != Controls[j].val);
          if(Controls[j].isChanged) {
            Controls[j].val = Controls[j].readingVal;
          }
        }
        Controls[j].lastVal = Controls[j].readingVal;
        break;
    }
  }
  // Handle interactions between hardware controls
  //
  correctControlStates();

  // Determine if at least one control has changed and set global variable
  //
  isControlChanged = false;
  for(int j=0; j<CONTROL_COUNT; j++) {
    if(Controls[j].isChanged)
      isControlChanged = true;
  }

  #ifdef LOG_INTERF_CHANGES
  if(isControlChanged) {
    for(int j=0; j<CONTROL_COUNT; j++) {
      SER_DEBUG.print(Controls[j].name);
      SER_DEBUG.print("=");
      SER_DEBUG.print(Controls[j].val, DEC);
      SER_DEBUG.print(" ");
    }
    SER_DEBUG.println();
  }
  #endif  
}

//--------------------------------------------------------------------------------
void updateProgramDialParams()
{
  // Calculate width of capacitance bins (of the program dial) for the
  // available number of programs
  //
  nCapBins = getAudioDABProgramCount();
//dCapBin  = (float)(Conf.maxCap -Conf.minCap)/nCapBins;

  SER_DEBUG.print(F("Program dial capacitance = "));
  SER_DEBUG.print(Conf.minCap, DEC);
  SER_DEBUG.print(F(" .. "));
  SER_DEBUG.print(Conf.maxCap, DEC);
  SER_DEBUG.print(F(" -> "));
//SER_DEBUG.print(dCapBin, 3);
//SER_DEBUG.print(F(" wide program bins"));
  calcProgBins(nCapBins, Conf.minCap, Conf.maxCap);
  SER_DEBUG.println();
}
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

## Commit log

2016-12-04 Added schematic
2016-12-13 First versions of board
2016-12-17 New pictures
    [DAB_Radio_v2a.fzz]
2016-12-23 OpenSCAD files for printed parts added
    [Radio_DAB_v2b.scad, Radio_MainBoard_v1.scad]
2017-01-14 Bug fix
    Prevent small changes in capacitance (Sender) led to constant switching
    of stations. Corrected this by allowing only changes with a difference
    >1
    [monkeyDAB_interface.ino]
2017-05-07 Quick fix of low station selection stability
    [monkeyDAB.ino, monkeyDAB_interface.ino]
2017-07-23 Bug fix
    Recall the last station when the radio is switched on and the tone-dial
    is on station-lock
    [monkeyDAB.ino, monkeyDAB_interface.ino]
